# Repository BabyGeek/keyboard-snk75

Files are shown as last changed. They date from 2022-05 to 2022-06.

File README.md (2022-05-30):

# keyboard SnK<sup>75</sup>

V1 prototype in progress

----

The name "SnK<sup>75</sup>" come from my online name MrSnkiiKyz and 75 because it is a 75% layout

### Pictures will go there when V1 prototype will be done

## Features scheduled
* The PCB
    * handle up to 84 MX Swicthes
    * USB-C connected
    * RGB backligt for each swicth (South facing)
    * RGB Underglow
    * programmable with QMK
* The Layout is ISO only (Layout legends based on MacOS ISO-FR layout)
* 7° Typing angle case

## Features done
* The keyboard layout YES - you can [check it there](http://www.keyboard-layout-editor.com/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é%0A%2F@%0A2&=%0A%0A%0A%22%0A%23%0A3&=%0A%0A%0A'%0A$%0A4&=%0A%0A%0A(%0A%25%0A5&=%0A%0A%0A§%0A%5E%0A6&=%0A%0A%0Aè%0A%2F&%0A7&=%0A%0A%0A!%0A*%0A8&=%0A%0A%0Aç%0A(%0A9&=%0A%0A%0Aà%0A)%0A0&=%25%0A%0A%0A)%0A%2F_%0A-&=%2F_%0A%0A%0A-%0A+%0A%2F=&_a:7&w:2%3B&=%0A%0A%0A%0ABackspace&=%0A%0A%0A%0AHome%3B&@_w:1.5%3B&=%0A%0A%0A%0ATab&_a:4%3B&=A%0A%0A%0A%0AQ&=Z%0A%0A%0A%0AW&=E%0A%0A%0A%0AE&=R%0A%0A%0A%0AR&=T%0A%0A%0A%0AT&=Y%0A%0A%0A%0AY&=U%0A%0A%0A%0AU&=I%0A%0A%0A%0AI&=O%0A%0A%0A%0AO&=P%0A%0A%0A%0AP&_a:0%3B&=¨%0A%0A%0A%5E%0A%7B%0A%5B&=*%0A%0A%0A€%0A%7D%0A%5D%0A%0A%0A%0A%0A$&_x:0.25&a:7&w:1.25&h:2&w2:1.5&h2:1&x2:-0.25%3B&=%0A%0A%0A%0AEnter&=%0A%0A%0A%0APage%20Up%3B&@_w:1.75%3B&=%0A%0A%0A%0ACaps%20Lock&_a:4%3B&=Q%0A%0A%0A%0AA&=S%0A%0A%0A%0AS&=D%0A%0A%0A%0AD&=F%0A%0A%0A%0AF&=G%0A%0A%0A%0AG&=H%0A%0A%0A%0AH&=J%0A%0A%0A%0AJ&=K%0A%0A%0A%0AK&=L%0A%0A%0A%0AL&_a:0%3B&=M%0A%0A%0A%0A%2F:%0A%2F%3B&=N%0A%0A%0A%0A%22%0A'&_a:4%3B&=£%0A%0A%0A%60&_x:1.25&a:7%3B&=%0A%0A%0A%0APage%20Down%3B&@_w:1.25%3B&=%0A%0A%0A%0AShift&_a:4%3B&=%3C%0A%0A%0A%3E&=W%0A%0A%0A%0AZ&=X%0A%0A%0A%0AX&=C%0A%0A%0A%0AC&=V%0A%0A%0A%0AV&=B%0A%0A%0A%0AB&=N%0A%0A%0A%0AN&=%3F%0A%0A%0A,%0AM&=.%0A,%0A%0A%2F%3B%0A%3C&=%2F%2F%0A.%0A%0A%2F:%0A%3E&_a:0%3B&=+%0A%0A%0A%2F=%0A%2F%2F%0A%3F&_a:7&w:1.75%3B&=%0A%0A%0A%0AShift&=%0A%0A%0A%0A↑&=%0A%0A%0A%0AEnd%3B&@_w:1.25%3B&=%0A%0A%0A%0ACtrl&_w:1.25%3B&=%0A%0A%0A%0AWin&_w:1.25%3B&=%0A%0A%0A%0AAlt&_w:6.25%3B&=&=%0A%0A%0A%0AAlt&=%0A%0A%0A%0AFn&=%0A%0A%0A%0ACtrl&=%0A%0A%0A%0A←&=%0A%0A%0A%0A↓&=%0A%0A%0A%0A→)

* The PCB schematics - YES it is supposed to be good
* The PCB Keys layout - YES
* The PCB Routes - In progress

### THEN 

* The PCB Prototype - Not yet
* Connectivity PCB Test - Not yet

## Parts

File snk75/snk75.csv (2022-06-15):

Comment | Designator | Footprint | LCSC Part #
100nF Unpolarized capacitor, small symbol | C1,C2,C3,C4,C5,C6,C7,C8,C9,C10,C11,C12,C13,C14,C15,C16,C17,C24,C26,C27,C28,C29 | C_0402_1005Metric | C1525
100nF Unpolarized capacitor, small symbol | C18 | C_0402_1005Metric_Pad0.74x0.62mm_HandSolder | C1525
1uF Unpolarized capacitor, small symbol | C25 | C_0402_1005Metric | C52923
4.7uF Unpolarized capacitor, small symbol | C30 | C_0402_1005Metric | C23733
1uF Unpolarized capacitor | C31,C34 | C_0805_2012Metric | C215803
10nF Unpolarized capacitor, small symbol | C33 | C_0402_1005Metric | C15195
1N4148W Diode, small symbol | D1,D2,D3,D4,D5,D6,D7,D8,D9,D10,D11,D12,D13,D14,D15,D16,D17,D18,D19,D20,D21,D22,D23,D24,D25,D26,D27,D28,D29,D30,D31,D32,D33,D34,D35,D36,D37,D38,D39,D40,D41,D42,D43,D44,D45,D46,D47,D48,D49,D50,D51,D52,D53,D54,D55,D56,D57,D58,D59,D60,D61,D62,D63,D64,D65,D66,D67,D68,D69,D70,D71,D72,D73,D74,D75,D76,D77,D78,D79,D80,D81,D82,D83,D84,D85 | D_SOD-123 | C81598
WS2812C-2020 Intelligent control RGB LED integrated light source, 3.5x3.5mm package | D86,D87,D88,D89,D90,D91,D92,D93,D94,D95,D96,D97,D98,D99,D100,D101 | LED_WS2812_2020 | C965556
B5819W-SL Schottky diode | D102 | D_SOD-123 | C8598
nSMD100-16V Fuse | F1 | Fuse_1206_3216Metric_Pad1.42x1.75mm_HandSolder | C70082
GZ2012D601TF Ferrite bead, small symbol | FB1 | L_0805_2012Metric | C1017
TYPE-C-31-M12 16-pin USB type C (USB 2.0) connector | J1 | TYPE-C-31-M-12 | C165948
AO3400A N-MOSFET transistor, gate/source/drain | Q1 | SOT-23 | C347475
680R Resistor, small symbol | R1,R2,R3,R4,R5,R6,R7,R8,R9,R10,R11,R12,R13,R14,R15,R16,R17,R18,R19,R20,R21,R22,R23,R24,R25,R26,R27,R28,R29,R30,R31,R32,R33,R34,R35,R36,R37,R38,R39,R40,R41,R42,R43,R44,R45,R46,R47,R48,R49,R50,R51,R52,R53,R54,R55,R56,R57,R58,R59,R60,R61,R62,R63,R64,R65,R66,R67,R68,R69,R70,R71,R72,R73,R74,R75,R76,R77,R78,R79,R80,R81,R82,R83,R84,R85 | R_0402_1005Metric | C433827
5.1R Resistor, small symbol | R86,R87,R88,R89,R90,R91,R92,R93,R94,R95,R96,R97,R98,R99,R100,R101 | R_0402_1005Metric | C25165
5.1k Resistor, small symbol | R104,R105 | R_0402_1005Metric | C25905
10k Resistor, small symbol | R106,R108 | R_0402_1005Metric | C269701
100R Resistor, small symbol | R107 | R_0402_1005Metric | C25076
100k Resistor | R109,R110 | R_0402_1005Metric | C149504
SW_Push_RST Push button switch, generic, two pins | SWP1 | SW_SPST_SKQG_WithStem | C318886
SW_Push_BOOT Push button switch, generic, two pins | SWP2 | SW_SPST_SKQG_WithStem | C318886
STM32F072C8Tx ARM Cortex-M0 MCU, 64KB flash, 16KB RAM, 48MHz, 2-3.6V, 37 GPIO, LQFP-48 | U1 | LQFP-48_7x7mm_P0.5mm | C80488
USBLC6-2SC6 Very low capacitance ESD protection diode, 2 data-line, SOT-23-6 | U3 | SOT-23-6_Handsoldering | C7519
SGM2007-3.3XN5/TR 300mA, Low Power, Low Dropout Linear Regulators | U4 | SOT-23-5_HandSoldering | C193687

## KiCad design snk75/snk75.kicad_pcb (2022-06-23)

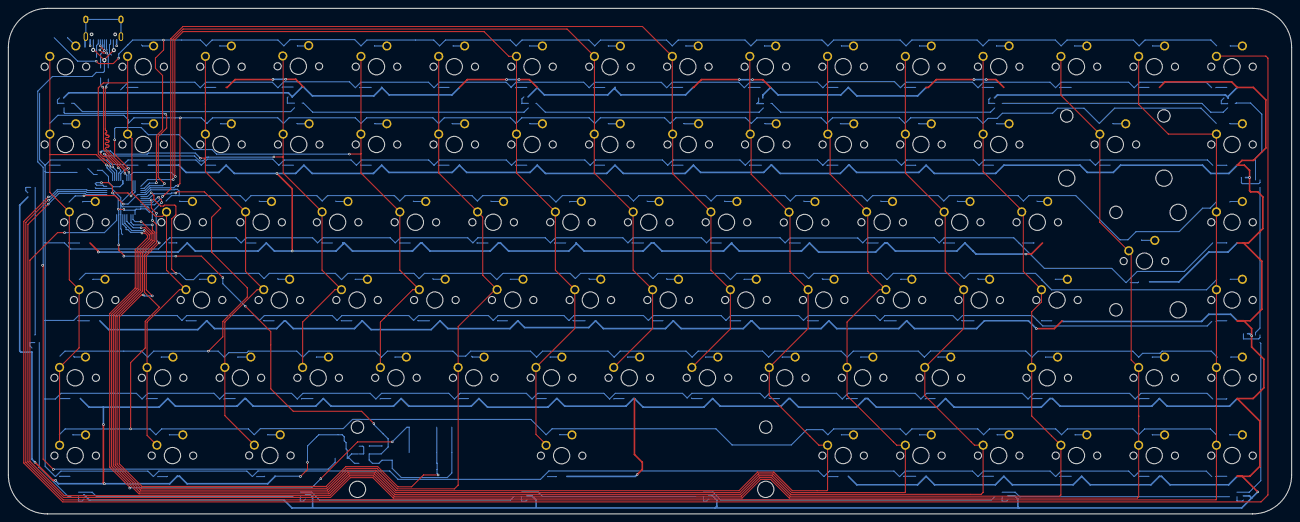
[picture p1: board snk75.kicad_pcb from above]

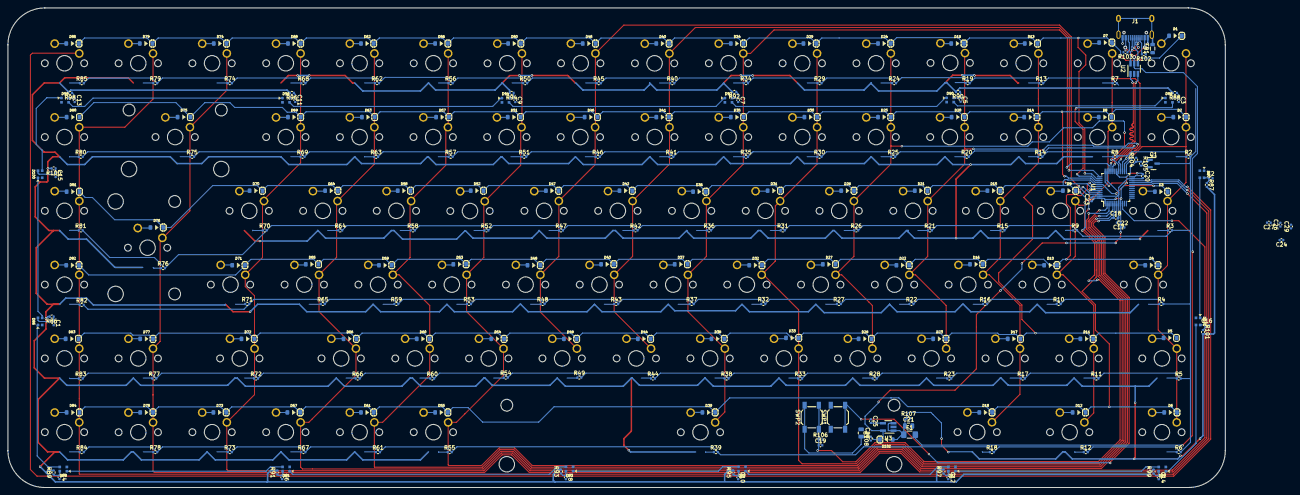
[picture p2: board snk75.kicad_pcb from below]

Board: 2 copper layers, 314.3 x 123.8 mm, 332 parts (247 on the bottom side), 156 nets.

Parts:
C1, C2, C3, C4, C5, C6, C7, C8, C9, C10, C11, C12, C13, C14, C15, C16, C17, C19, C23, C24, C26: 100nF; C_0402_1005Metric
C18: 100nF; C_0402_1005Metric_Pad0.74x0.62mm_HandSolder
C20: 1uF; C_0402_1005Metric
C21, C28: 1uF; C_0805_2012Metric
C22, C25: 10nF; C_0402_1005Metric
C27, C29: 4.7uF; C_0402_1005Metric
D1, D2, D3, D4, D5, D6, D7, D8, D9, D10, D11, D12, D13, D14, D15, D16, D17, D18, D19, D20, D21, D22, D23, D24, D25, D26, D27, D28, D29, D30, D31, D32, D33, D34, D35, D36, D37, D38, D39, D40, D41, D42, D43, D44, D45, D46, D47, D48, D49, D50, D51, D52, D53, D54, D55, D56, D57, D58, D59, D60, D61, D62, D63, D64, D65, D66, D67, D68, D69, D70, D71, D72, D73, D74, D75, D76, D77, D78, D79, D80, D81, D82, D83, D84, D85: 1N4148W; D_SOD-123
D86, D87, D88, D89, D90, D91, D92, D93, D94, D95, D96, D97, D98, D99, D100, D101: WS2812C-2020; LED_WS2812_2020
D102: B5819W-SL; D_SOD-123
F1: nSMD100-16V; Fuse_1206_3216Metric_Pad1.42x1.75mm_HandSolder
FB1: GZ2012D601TF; L_0805_2012Metric
J1: TYPE-C-31-M12; TYPE-C-31-M-12
MX1: Esc; MXOnly-1U-NoLED
MX2: @; MXOnly-1U-NoLED
MX3: Tab_15; MXOnly-1.5U-NoLED
MX4: Caps_175; MXOnly-1.75U-NoLED
MX5: LShift_125; MXOnly-1.25U-NoLED
MX6: Ctrl_125; MXOnly-1.25U-NoLED
MX7: F1; MXOnly-1U-NoLED
MX8: 1; MXOnly-1U-NoLED
MX9: A; MXOnly-1U-NoLED
MX10: Q; MXOnly-1U-NoLED
MX11: >; MXOnly-1U-NoLED
MX12: L_Opt_125; MXOnly-1.25U-NoLED
MX13: F2; MXOnly-1U-NoLED
MX14: 2; MXOnly-1U-NoLED
MX15: Z; MXOnly-1U-NoLED
MX16: S; MXOnly-1U-NoLED
MX17: W; MXOnly-1U-NoLED
MX18: L_Cmd_125; MXOnly-1.25U-NoLED
MX19: F3; MXOnly-1U-NoLED
MX20: 3; MXOnly-1U-NoLED
MX21: E; MXOnly-1U-NoLED
MX22: D; MXOnly-1U-NoLED
MX23: X; MXOnly-1U-NoLED
MX24: F4; MXOnly-1U-NoLED
MX25: 4; MXOnly-1U-NoLED
MX26: R; MXOnly-1U-NoLED
MX27: F; MXOnly-1U-NoLED
MX28: C; MXOnly-1U-NoLED
MX29: F5; MXOnly-1U-NoLED
MX30: 5; MXOnly-1U-NoLED
MX31: T; MXOnly-1U-NoLED
MX32: G; MXOnly-1U-NoLED
MX33: V; MXOnly-1U-NoLED
MX34: F6; MXOnly-1U-NoLED
MX35: 6; MXOnly-1U-NoLED
MX36: Y; MXOnly-1U-NoLED
MX37: H; MXOnly-1U-NoLED
MX38: B; MXOnly-1U-NoLED
MX39: Space_625; MXOnly-6.25U-NoLED
MX40: F7; MXOnly-1U-NoLED
MX41: 7; MXOnly-1U-NoLED
MX42: U; MXOnly-1U-NoLED
MX43: J; MXOnly-1U-NoLED
MX44: N; MXOnly-1U-NoLED
MX45: F8; MXOnly-1U-NoLED
MX46: 8; MXOnly-1U-NoLED
MX47: I; MXOnly-1U-NoLED
MX48: K; MXOnly-1U-NoLED
MX49: ?; MXOnly-1U-NoLED
MX50: F9; MXOnly-1U-NoLED
MX51: 9; MXOnly-1U-NoLED
MX52: O; MXOnly-1U-NoLED
MX53: L; MXOnly-1U-NoLED
MX54: .; MXOnly-1U-NoLED
MX55: R_Cmd; MXOnly-1U-NoLED
MX56: F10; MXOnly-1U-NoLED
MX57: 0; MXOnly-1U-NoLED
MX58: P; MXOnly-1U-NoLED
MX59: M; MXOnly-1U-NoLED
MX60: /; MXOnly-1U-NoLED
MX61: FN; MXOnly-1U-NoLED
MX62: F11; MXOnly-1U-NoLED
MX63: ); MXOnly-1U-NoLED
MX64: ¨; MXOnly-1U-NoLED
MX65: %; MXOnly-1U-NoLED
MX66: +; MXOnly-1U-NoLED
MX67: R_Opt; MXOnly-1U-NoLED
MX68: F12; MXOnly-1U-NoLED
MX69: -; MXOnly-1U-NoLED
MX70: *; MXOnly-1U-NoLED
MX71: £; MXOnly-1U-NoLED
MX72: RShift_175; MXOnly-1.75U-NoLED
MX73: A_L; MXOnly-1U-NoLED
MX74: F13; MXOnly-1U-NoLED
MX75: BckSpc_2; MXOnly-2U-NoLED
MX76: Enter_ISO_125_2; MXOnly-ISO-NoLED
MX77: A_UP; MXOnly-1U-NoLED
MX78: A_DWN; MXOnly-1U-NoLED
MX79: F14; MXOnly-1U-NoLED
MX80: Home; MXOnly-1U-NoLED
MX81: PgUp; MXOnly-1U-NoLED
MX82: PgDown; MXOnly-1U-NoLED
MX83: End; MXOnly-1U-NoLED
MX84: A_R; MXOnly-1U-NoLED
MX85: F15; MXOnly-1U-NoLED
Q1: AO3400A; SOT-23
R2, R3, R4, R5, R6, R7, R8, R9, R10, R11, R12, R13, R14, R15, R16, R17, R18, R19, R20, R21, R22, R23, R24, R25, R26, R27, R28, R29, R30, R31, R32, R33, R34, R35, R36, R37, R38, R39, R40, R41, R42, R43, R44, R45, R46, R47, R48, R49, R50, R51, R52, R53, R54, R55, R56, R57, R58, R59, R60, R61, R62, R63, R64, R65, R66, R67, R68, R69, R70, R71, R72, R73, R74, R75, R76, R77, R78, R79, R80, R81, R82, R83, R84, R85: 680R; R_0402_1005Metric
R86, R87, R88, R89, R90, R91, R92, R93, R94, R95, R96, R97, R98, R99, R100, R101: 5.1R; R_0402_1005Metric
R102, R103: 5.1k; R_0402_1005Metric
R104, R106: 10k; R_0402_1005Metric
R105: 100R; R_0402_1005Metric
R107, R108: 100k; R_0402_1005Metric
SWP1: SW_Push_RST; SW_SPST_SKQG_WithStem
SWP2: SW_Push_BOOT; SW_SPST_SKQG_WithStem
U1: STM32F072C8Tx; LQFP-48_7x7mm_P0.5mm
U2: USBLC6-2SC6; SOT-23-6_Handsoldering
U3: SGM2007-3.3XN5/TR; SOT-23-5_HandSoldering

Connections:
+3V3: C17.1, C20.1, C22.1, C23.1, C24.1, C26.1, C27.1, C28.2, C29.1, D102.1 (K), R108.2, SWP2.1, U1.1 (VBAT), U1.9 (VDDA), U1.24 (VDD), U1.36 (VDDIO2), U1.48 (VDD), U3.5 (OUT)
+5V: C21.1, D102.2 (A), F1.1, R86.2, R87.2, R88.2, R89.2, R90.2, R91.2, R92.2, R93.2, R94.2, R95.2, R96.2, R97.2, R98.2, R99.2, R100.2, R101.2, R107.1, U3.1 (IN), U3.3 (EN)
BOOT: C19.1, R106.1, SWP2.2, U1.44 (BOOT0)
D+: U1.33 (PA12), U2.1 (I/O1)
D-: U1.32 (PA11), U2.3 (I/O2)
DBUS+: J1.A6 (D+), J1.B6 (D+), U2.6 (I/O1)
DBUS-: J1.A7 (D-), J1.B7 (D-), U2.4 (I/O2)
GND: C1.2, C2.2, C3.2, C4.2, C5.2, C6.2, C7.2, C8.2, C9.2, C10.2, C11.2, C12.2, C13.2, C14.2, C15.2, C16.2, C17.2, C18.2, C19.2, C20.2, C21.2, C22.2, C23.2, C24.2, C25.1, C26.2, C27.2, C28.1, C29.2, D86.2 (VSS), D87.2 (VSS), D88.2 (VSS), D89.2 (VSS), D90.2 (VSS), D91.2 (VSS), D92.2 (VSS), D93.2 (VSS), D94.2 (VSS), D95.2 (VSS), D96.2 (VSS), D97.2 (VSS), D98.2 (VSS), D99.2 (VSS), D100.2 (VSS), D101.2 (VSS), FB1.1, J1.A1 (GND), J1.B1 (GND), Q1.2 (S), R102.1, R103.2, R104.2, R106.2, R107.2, R108.1, SWP1.1, U1.8 (VSSA), U1.23 (VSS), U1.35 (VSS), U1.47 (VSS), U2.2 (GND), U3.2 (GND)
GNDPWR: FB1.2, J1.S (SHIELD)
LED-: Q1.3 (D), R2.2, R3.2, R4.2, R5.2, R6.2, R7.2, R8.2, R9.2, R10.2, R11.2, R12.2, R13.2, R14.2, R15.2, R16.2, R17.2, R18.2, R19.2, R20.2, R21.2, R22.2, R23.2, R24.2, R25.2, R26.2, R27.2, R28.2, R29.2, R30.2, R31.2, R32.2, R33.2, R34.2, R35.2, R36.2, R37.2, R38.2, R39.2, R40.2, R41.2, R42.2, R43.2, R44.2, R45.2, R46.2, R47.2, R48.2, R49.2, R50.2, R51.2, R52.2, R53.2, R54.2, R55.2, R56.2, R57.2, R58.2, R59.2, R60.2, R61.2, R62.2, R63.2, R64.2, R65.2, R66.2, R67.2, R68.2, R69.2, R70.2, R71.2, R72.2, R73.2, R74.2, R75.2, R76.2, R77.2, R78.2, R79.2, R80.2, R81.2, R82.2, R83.2, R84.2, R85.2
LED_PWM: R104.1, R105.1, U1.30 (PA9)
unnamed: C1.1, D86.4 (VDD), R86.1
unnamed: C2.1, D87.4 (VDD), R87.1
unnamed: C3.1, D88.4 (VDD), R88.1
unnamed: C4.1, D89.4 (VDD), R89.1
unnamed: C5.1, D90.4 (VDD), R90.1
unnamed: C6.1, D91.4 (VDD), R91.1
unnamed: C7.1, D92.4 (VDD), R92.1
unnamed: C8.1, D93.4 (VDD), R93.1
unnamed: C9.1, D94.4 (VDD), R94.1
unnamed: C10.1, D95.4 (VDD), R95.1
unnamed: C11.1, D96.4 (VDD), R96.1
unnamed: C12.1, D97.4 (VDD), R97.1
unnamed: C13.1, D98.4 (VDD), R98.1
unnamed: C14.1, D99.4 (VDD), R99.1
unnamed: C15.1, D100.4 (VDD), R100.1
unnamed: C16.1, D101.4 (VDD), R101.1
unnamed: C25.2, U3.4 (BP/FB)
unnamed: D1.2 (A), MX1.2 (ROW)
unnamed: D2.2 (A), MX2.2 (ROW)
unnamed: D3.2 (A), MX3.2 (ROW)
unnamed: D4.2 (A), MX4.2 (ROW)
unnamed: D5.2 (A), MX5.2 (ROW)
unnamed: D6.2 (A), MX6.2 (ROW)
unnamed: D7.2 (A), MX7.2 (ROW)
unnamed: D8.2 (A), MX8.2 (ROW)
unnamed: D9.2 (A), MX9.2 (ROW)
unnamed: D10.2 (A), MX10.2 (ROW)
unnamed: D11.2 (A), MX11.2 (ROW)
unnamed: D12.2 (A), MX12.2 (ROW)
unnamed: D13.2 (A), MX13.2 (ROW)
unnamed: D14.2 (A), MX14.2 (ROW)
unnamed: D15.2 (A), MX15.2 (ROW)
unnamed: D16.2 (A), MX16.2 (ROW)
unnamed: D17.2 (A), MX17.2 (ROW)
unnamed: D18.2 (A), MX18.2 (ROW)
unnamed: D19.2 (A), MX19.2 (ROW)
unnamed: D20.2 (A), MX20.2 (ROW)
unnamed: D21.2 (A), MX21.2 (ROW)
unnamed: D22.2 (A), MX22.2 (ROW)
unnamed: D23.2 (A), MX23.2 (ROW)
unnamed: D24.2 (A), MX24.2 (ROW)
unnamed: D25.2 (A), MX25.2 (ROW)
unnamed: D26.2 (A), MX26.2 (ROW)
unnamed: D27.2 (A), MX27.2 (ROW)
unnamed: D28.2 (A), MX28.2 (ROW)
unnamed: D29.2 (A), MX29.2 (ROW)
unnamed: D30.2 (A), MX30.2 (ROW)
unnamed: D31.2 (A), MX31.2 (ROW)
unnamed: D32.2 (A), MX32.2 (ROW)
unnamed: D33.2 (A), MX33.2 (ROW)
unnamed: D34.2 (A), MX34.2 (ROW)
unnamed: D35.2 (A), MX35.2 (ROW)
unnamed: D36.2 (A), MX36.2 (ROW)
unnamed: D37.2 (A), MX37.2 (ROW)
unnamed: D38.2 (A), MX38.2 (ROW)
unnamed: D39.2 (A), MX39.2 (ROW)
unnamed: D40.2 (A), MX40.2 (ROW)
unnamed: D41.2 (A), MX41.2 (ROW)
unnamed: D42.2 (A), MX42.2 (ROW)
unnamed: D43.2 (A), MX43.2 (ROW)
unnamed: D44.2 (A), MX44.2 (ROW)
unnamed: D45.2 (A), MX45.2 (ROW)
unnamed: D46.2 (A), MX46.2 (ROW)
unnamed: D47.2 (A), MX47.2 (ROW)
unnamed: D48.2 (A), MX48.2 (ROW)
unnamed: D49.2 (A), MX49.2 (ROW)
unnamed: D50.2 (A), MX50.2 (ROW)
unnamed: D51.2 (A), MX51.2 (ROW)
unnamed: D52.2 (A), MX52.2 (ROW)
unnamed: D53.2 (A), MX53.2 (ROW)
unnamed: D54.2 (A), MX54.2 (ROW)
unnamed: D55.2 (A), MX55.2 (ROW)
unnamed: D56.2 (A), MX56.2 (ROW)
unnamed: D57.2 (A), MX57.2 (ROW)
unnamed: D58.2 (A), MX58.2 (ROW)
unnamed: D59.2 (A), MX59.2 (ROW)
unnamed: D60.2 (A), MX60.2 (ROW)
unnamed: D61.2 (A), MX61.2 (ROW)
unnamed: D62.2 (A), MX62.2 (ROW)
unnamed: D63.2 (A), MX63.2 (ROW)
unnamed: D64.2 (A), MX64.2 (ROW)
unnamed: D65.2 (A), MX65.2 (ROW)
unnamed: D66.2 (A), MX66.2 (ROW)
unnamed: D67.2 (A), MX67.2 (ROW)
unnamed: D68.2 (A), MX68.2 (ROW)
unnamed: D69.2 (A), MX69.2 (ROW)
unnamed: D70.2 (A), MX70.2 (ROW)
unnamed: D71.2 (A), MX71.2 (ROW)
unnamed: D72.2 (A), MX72.2 (ROW)
unnamed: D73.2 (A), MX73.2 (ROW)
unnamed: D74.2 (A), MX74.2 (ROW)
unnamed: D75.2 (A), MX75.2 (ROW)
unnamed: D76.2 (A), MX76.2 (ROW)
unnamed: D77.2 (A), MX77.2 (ROW)
unnamed: D78.2 (A), MX78.2 (ROW)
unnamed: D79.2 (A), MX79.2 (ROW)
unnamed: D80.2 (A), MX80.2 (ROW)
unnamed: D81.2 (A), MX81.2 (ROW)
unnamed: D82.2 (A), MX82.2 (ROW)
unnamed: D83.2 (A), MX83.2 (ROW)
unnamed: D84.2 (A), MX84.2 (ROW)
unnamed: D85.2 (A), MX85.2 (ROW)
unnamed: D86.1 (DOUT), D89.3 (DIN)
unnamed: D88.1 (DOUT), D90.3 (DIN)
unnamed: D89.1 (DOUT), D91.3 (DIN)
unnamed: D90.1 (DOUT), D92.3 (DIN)
unnamed: D91.1 (DOUT), D93.3 (DIN)
unnamed: D92.1 (DOUT), D94.3 (DIN)
unnamed: D93.1 (DOUT), D95.3 (DIN)
unnamed: D94.1 (DOUT), D96.3 (DIN)
unnamed: D95.1 (DOUT), D97.3 (DIN)
unnamed: D96.1 (DOUT), D98.3 (DIN)
unnamed: D97.1 (DOUT), D99.3 (DIN)
unnamed: D86.3 (DIN), D100.1 (DOUT)
unnamed: D98.1 (DOUT), D100.3 (DIN)
unnamed: D87.3 (DIN), D101.1 (DOUT)
unnamed: D99.1 (DOUT), D101.3 (DIN)
unnamed: J1.A5 (CC1), R102.2
unnamed: J1.B5 (CC2), R103.1
unnamed: Q1.1 (G), R105.2
RST: C18.1, SWP1.2, U1.7 (NRST)
UGLED: D88.3 (DIN), U1.39 (PB3)
VBUS: F1.2, J1.A4 (VBUS), J1.B4 (VBUS), U2.5 (VBUS)
col1: MX1.1 (COL), MX2.1 (COL), MX3.1 (COL), MX4.1 (COL), MX5.1 (COL), MX6.1 (COL), U1.25 (PB12)
col2: MX7.1 (COL), MX8.1 (COL), MX9.1 (COL), MX10.1 (COL), MX11.1 (COL), MX12.1 (COL), U1.26 (PB13)
col3: MX13.1 (COL), MX14.1 (COL), MX15.1 (COL), MX16.1 (COL), MX17.1 (COL), MX18.1 (COL), U1.27 (PB14)
col4: MX19.1 (COL), MX20.1 (COL), MX21.1 (COL), MX22.1 (COL), MX23.1 (COL), U1.28 (PB15)
col5: MX24.1 (COL), MX25.1 (COL), MX26.1 (COL), MX27.1 (COL), MX28.1 (COL), U1.29 (PA8)
col6: MX29.1 (COL), MX30.1 (COL), MX31.1 (COL), MX32.1 (COL), MX33.1 (COL), U1.3 (PC14)
col7: MX34.1 (COL), MX35.1 (COL), MX36.1 (COL), MX37.1 (COL), MX38.1 (COL), MX39.1 (COL), U1.34 (PA13)
col8: MX40.1 (COL), MX41.1 (COL), MX42.1 (COL), MX43.1 (COL), MX44.1 (COL), U1.37 (PA14)
col9: MX45.1 (COL), MX46.1 (COL), MX47.1 (COL), MX48.1 (COL), MX49.1 (COL), U1.46 (PB9)
col10: MX50.1 (COL), MX51.1 (COL), MX52.1 (COL), MX53.1 (COL), MX54.1 (COL), MX55.1 (COL), U1.2 (PC13)
col11: MX56.1 (COL), MX57.1 (COL), MX58.1 (COL), MX59.1 (COL), MX60.1 (COL), MX61.1 (COL), U1.5 (PF0)
col12: MX62.1 (COL), MX63.1 (COL), MX64.1 (COL), MX65.1 (COL), MX66.1 (COL), MX67.1 (COL), U1.6 (PF1)
col13: MX68.1 (COL), MX69.1 (COL), MX70.1 (COL), MX71.1 (COL), MX72.1 (COL), MX73.1 (COL), U1.10 (PA0)
col14: MX74.1 (COL), MX75.1 (COL), MX76.1 (COL), MX77.1 (COL), MX78.1 (COL), U1.20 (PB2)
col15: MX79.1 (COL), MX80.1 (COL), MX81.1 (COL), MX82.1 (COL), MX83.1 (COL), MX84.1 (COL), U1.21 (PB10)
col16: MX85.1 (COL), U1.22 (PB11)
row1: D1.1 (K), D7.1 (K), D13.1 (K), D19.1 (K), D24.1 (K), D29.1 (K), D34.1 (K), D40.1 (K), D45.1 (K), D50.1 (K), D56.1 (K), D62.1 (K), D68.1 (K), D74.1 (K), D79.1 (K), D85.1 (K), U1.38 (PA15)
row2: D2.1 (K), D8.1 (K), D14.1 (K), D20.1 (K), D25.1 (K), D30.1 (K), D35.1 (K), D41.1 (K), D46.1 (K), D51.1 (K), D57.1 (K), D63.1 (K), D69.1 (K), D75.1 (K), D80.1 (K), U1.40 (PB4)
row3: D3.1 (K), D9.1 (K), D15.1 (K), D21.1 (K), D26.1 (K), D31.1 (K), D36.1 (K), D42.1 (K), D47.1 (K), D52.1 (K), D58.1 (K), D64.1 (K), D70.1 (K), D76.1 (K), D81.1 (K), U1.41 (PB5)
row4: D4.1 (K), D10.1 (K), D16.1 (K), D22.1 (K), D27.1 (K), D32.1 (K), D37.1 (K), D43.1 (K), D48.1 (K), D53.1 (K), D59.1 (K), D65.1 (K), D71.1 (K), D82.1 (K), U1.42 (PB6)
row5: D5.1 (K), D11.1 (K), D17.1 (K), D23.1 (K), D28.1 (K), D33.1 (K), D38.1 (K), D44.1 (K), D49.1 (K), D54.1 (K), D60.1 (K), D66.1 (K), D72.1 (K), D77.1 (K), D83.1 (K), U1.43 (PB7)
row6: D6.1 (K), D12.1 (K), D18.1 (K), D39.1 (K), D55.1 (K), D61.1 (K), D67.1 (K), D73.1 (K), D78.1 (K), D84.1 (K), U1.45 (PB8)

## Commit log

2022-05-26 Added PCB started project
    [snk75.kicad_pcb, snk75.kicad_sch]
2022-05-26 Add ubc c connector
    [snk75.kicad_sch]
2022-05-26 Start keys layout
    [keys.kicad_sch, snk75.csv, snk75.kicad_pcb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]
2022-05-26 feat: keyboard keys
    [keys.kicad_sch, snk75.kicad_sch]
2022-05-27 Added submodules footprints, and devided main pcb into pin sheets
    [keys.kicad_sch]
2022-05-27 Add keys row 2
    [keys.kicad_sch, snk75.kicad_sch]
2022-05-27 Added other keys
    [keys.kicad_sch, snk75.kicad_sch]
2022-05-27 Added u for not 1 unit keys
    [keys.kicad_sch, snk75.kicad_sch]
2022-05-27 Added u for not space
    [keys.kicad_sch, snk75.kicad_sch]
2022-05-27 Added footprints for units more than 1
    [keys.kicad_sch, snk75.kicad_sch]
2022-05-27 Began PCB design
    [keys.kicad_sch, snk75.kicad_pcb, snk75.kicad_sch]
2022-05-27 Switch layout on PCB Editor
    [snk75.kicad_sch]
2022-05-27 Added PCB rounded borders
    [snk75.kicad_pcb]
2022-05-27 Fixed reset
    [keys.kicad_sch, snk75.kicad_pcb, snk75.kicad_sch]
2022-05-27 Fixed label
    [keys.kicad_sch, snk75.kicad_sch]
2022-05-28 Began routing
    [keys.kicad_sch, snk75.kicad_pcb, snk75.kicad_sch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]
2022-05-29 Changed MCU for STM32F072C8Tx and wired cols and rows
    [MCU.kicad_sch, components.kicad_sch, keys.kicad_sch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]
2022-05-30 added new row layout and connected row1 to MCU
    [MCU.kicad_sch, components.kicad_sch, keys.kicad_sch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]
2022-05-30 fixed alignment for unused pins
    [MCU.kicad_sch, components.kicad_sch, underglow.kicad_sch]
2022-05-30 added components on board and began routing
    [MCU.kicad_sch, components.kicad_sch, keys.kicad_sch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]
2022-05-31 Added some routes and finished to align components on switches
    [snk75.kicad_pcb]
2022-05-31 routed all rows and backlight RGB
    [snk75.kicad_pcb]
2022-05-31 Routed rows to MCU and began cols
    [snk75.kicad_pcb]
2022-06-01 WIP: Removed wrong path, gonna rebuild with better designed path
    [components.kicad_sch, snk75.kicad_pcb, snk75.kicad_sch]
2022-06-01 Re routed paths for cols and rows
    [MCU.kicad_sch]
2022-06-06 WIP routes
    [components.kicad_sch, snk75.kicad_sch]
2022-06-06 WIP(3D models): added R1 models
    [snk75.kicad_pcb]
2022-06-15 Nearly make all paths
    [MCU.kicad_sch, components.kicad_sch, keys.kicad_sch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]
2022-06-23 WIP: replacing backlight LEDs with RGB LEDs
    [keys.kicad_sch, snk75.kicad_pcb, snk75.kicad_sch]
2022-06-23 WIP: made all old LEDs no-connecting flags
    [keys.kicad_sch]
